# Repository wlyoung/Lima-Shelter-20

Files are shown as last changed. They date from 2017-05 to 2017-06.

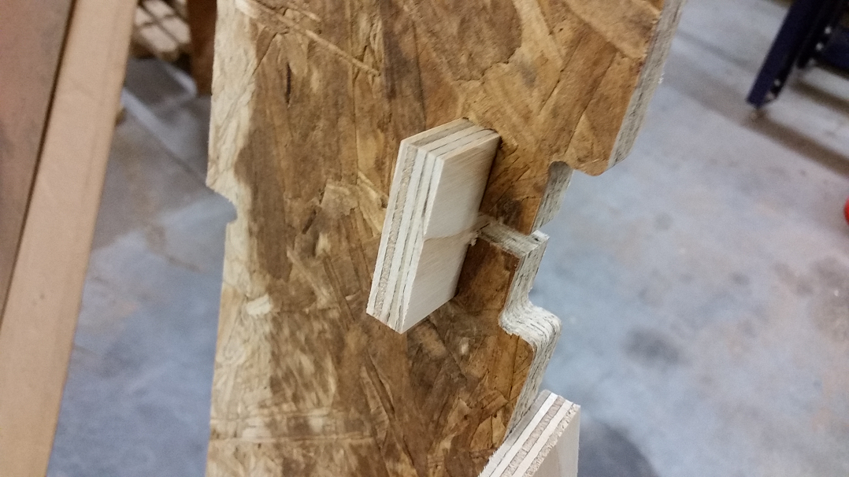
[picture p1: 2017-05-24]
images/fastener block in slot.png

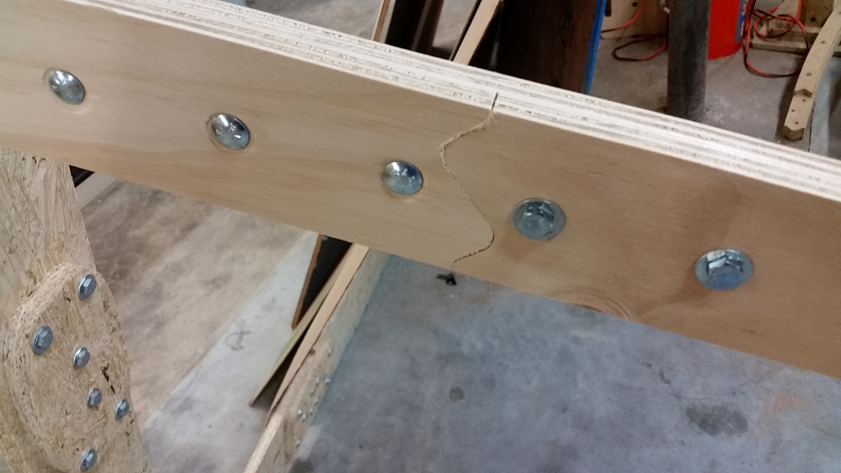
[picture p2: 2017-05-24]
images/carriage and hex bolts in splice plate.png

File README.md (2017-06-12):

# Lima Shelter 2.0

## About
Update of the Shelter 2.0 design to simplify the construction and and reduce material usage, using design details in the smaller 8x8 Shelter 2.0 design. 

Although several of the parts have been fabricated, a complete structure hasn't been built from thus design yet so there could be problems. Consider yourselves warned.

And just because someone will ask, it was named for the city in Peru and not the bean.

## Changes and issues

* The Lima Shelter has 2 more sheets of 1/2" material, but 11 less sheets of 3/4". 

* Everything is cut with a 1/4" bit

* The files are somewhat material agnostic, and can be made from material that's close to the designed size

* The half-lap connections in the rib parts have been replaced with bolted splice plates. They are both easier to assemble and much faster to cut

* The longitudinal slotted stringers that connect the ribs have been replaced with purlins that are fastened with screws into small plywood "wedges" that are cut from some of the 1/2" sheets. This allows the ribs to be narrower, giving more interior room. The use of these wedges allow us to fasten into the face of plywood instead of the edge, a much stronger connection.

* Shallow dimples (on their own layer in the files) mark the location of pilot holes for the screws. You can se these dimples to drill through holes with a hand drill and a bit sized for your crews, or tollpath tham as thru-holes and drill them with a seperate bit

* There's now one door instead of two...2 doors ended up being a pain! This also allowed us to create a solid wall version that only requires a few cutting mods, and mounting the trim pieces on the outside of the endwall, instead of on the inside for a door. The Sketchup model should help illustrate that

* This version doesn't have any windows. We haven't come up with a great idea for them and figured we would see what others came up with.

* Most of the bolts are now 1/4" or 6mm, and can be either hex bolts or carriage bolts (preferred). The only exception are the bolts holding the sleepers together...they are still 3/8". If using Hex bolts we recommend using flat washers under the head, and regardless of what kind of bolt you use, a washer under the nut is always a good idea.

* Several pieces of AtFAB furniture have been added to the waste areas of some of the 3/4" sheets. Thanks SO much to Ann and Gary for allowing us to include their designs. You may ONLY cut their furniture along with these Shelter files...if you want to cut more contact them at http://atfab.co/

* This work is licensed under the Creative Commons Attribution-NonCommercial 3.0 International License. To view a copy of this license, visit http://creativecommons.org/licenses/by-nc/3.0/ or send a letter to Creative Commons, PO Box 1866, Mountain View, CA 94042, USA.

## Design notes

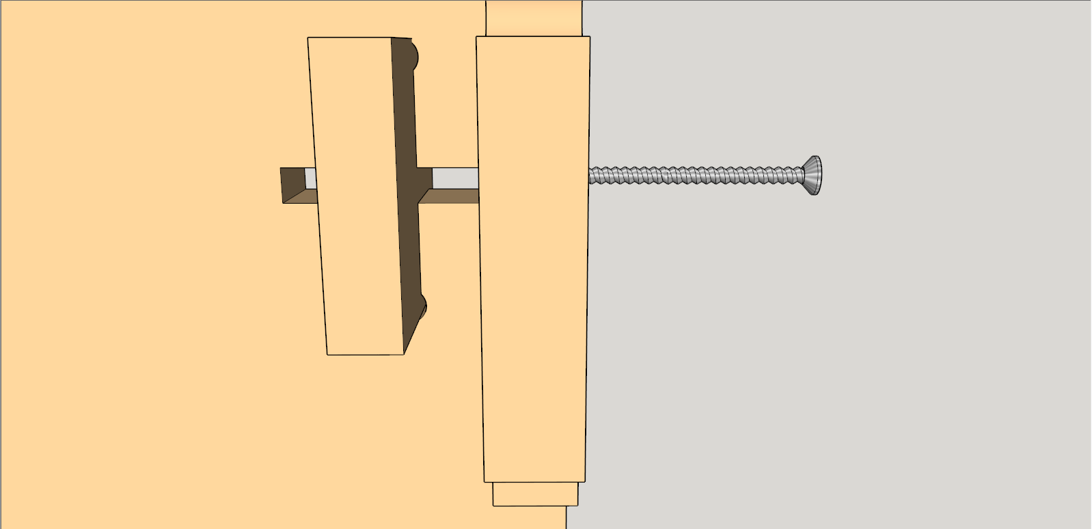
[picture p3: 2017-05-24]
images/attach purlins 2.png

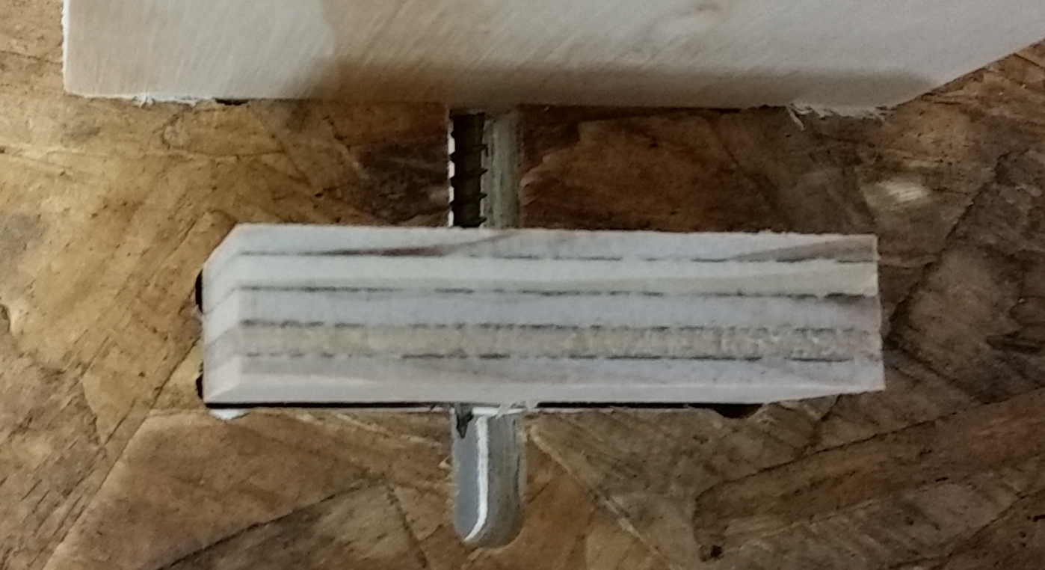
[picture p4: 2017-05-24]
images/screw detail.png

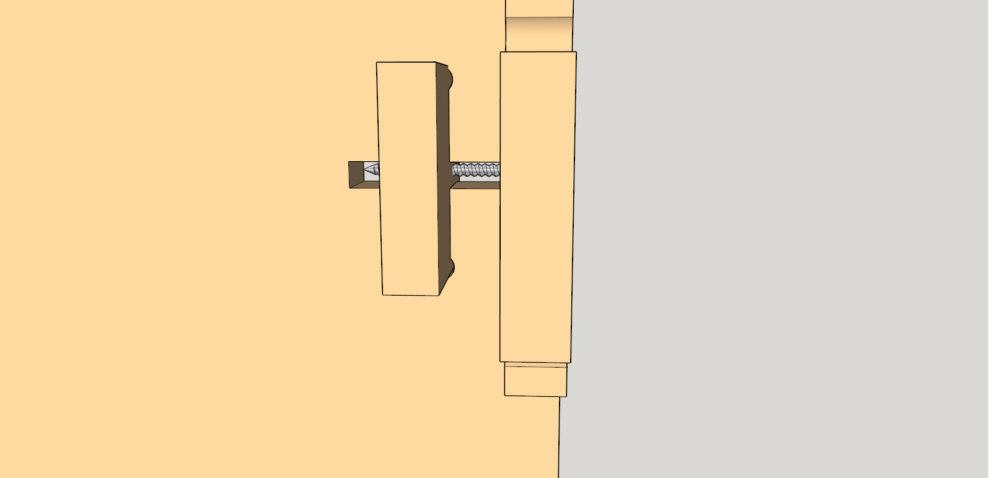
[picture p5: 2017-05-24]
images/attach purlins 3.png

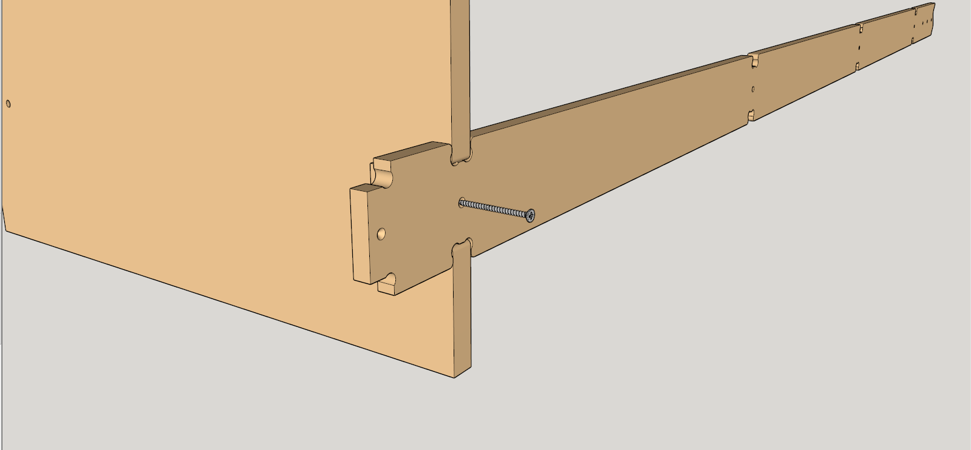
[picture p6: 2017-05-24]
images/attach purlins 1.png

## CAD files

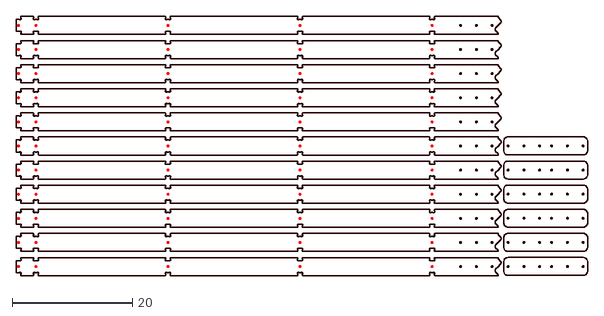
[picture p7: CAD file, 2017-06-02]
dxf/half inch/Lima Purlin cut 2.dxf
95.2 x 43.2

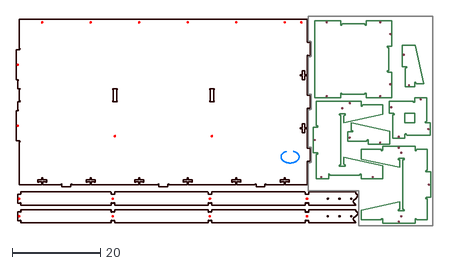
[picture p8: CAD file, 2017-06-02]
dxf/three quarter/Lima Floor edge short C and floor splice cut 1.dxf
94.5 x 47.5

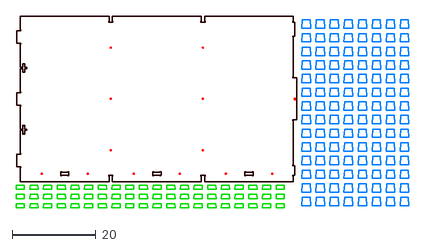
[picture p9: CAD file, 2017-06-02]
dxf/half inch/Lima Sidewall short and wedges cut 2.dxf
93.8 x 45.8

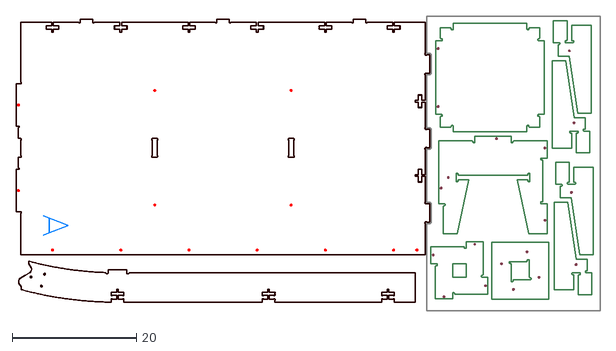
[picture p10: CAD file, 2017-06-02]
dxf/three quarter/Lima Floor edge short A and fascia cut 1.dxf
94.2 x 47.5

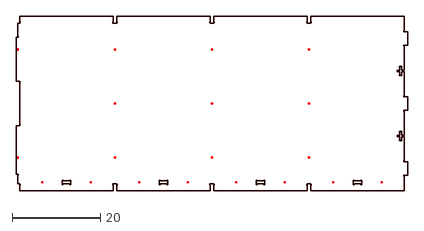
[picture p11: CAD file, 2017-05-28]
dxf/half inch/Lima Sidewall long cut 2.dxf
88.8 x 39.5

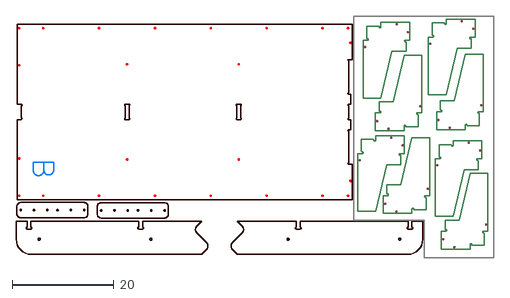
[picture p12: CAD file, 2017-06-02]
dxf/three quarter/Lima Floor center short B and sleeper parts and floor splice joiners cut 1.dxf
94.0 x 47.5

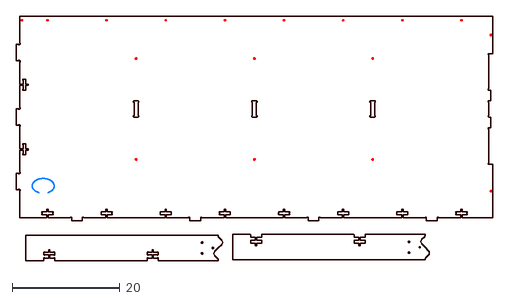
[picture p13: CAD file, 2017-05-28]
dxf/three quarter/Lima Floor edge long C and fascia cut 1.dxf
88.7 x 45.5

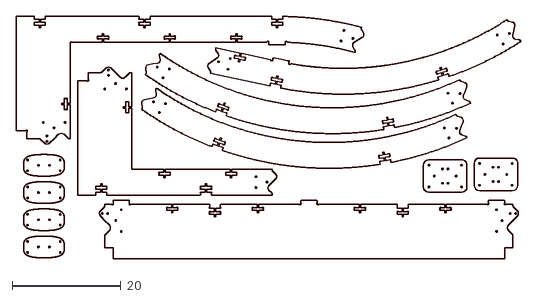
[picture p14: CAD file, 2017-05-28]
dxf/three quarter/Lima Ribs cut 6.dxf
92.8 x 44.6

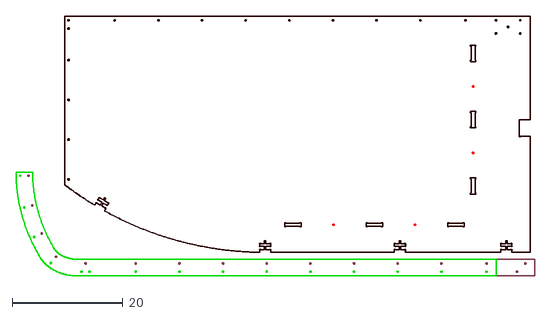
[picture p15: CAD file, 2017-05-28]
dxf/three quarter/Lima Endwall left cut 2.dxf
93.9 x 47.0

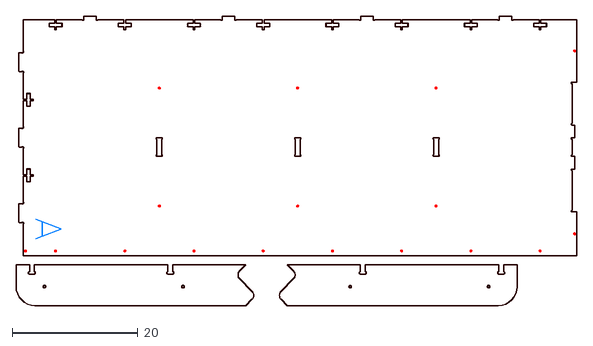
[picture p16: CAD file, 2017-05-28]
dxf/three quarter/Lima Floor edge long A and sleeper parts cut 1.dxf
89.1 x 45.9

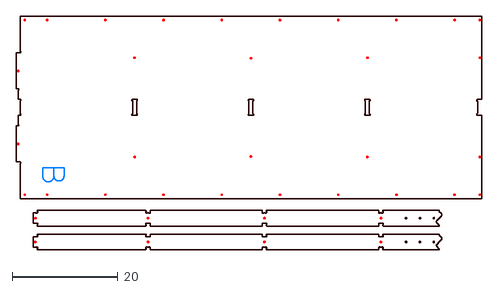
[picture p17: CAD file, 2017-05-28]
dxf/three quarter/Lima Floor center long B and floor splice cut 1.dxf
88.0 x 44.2

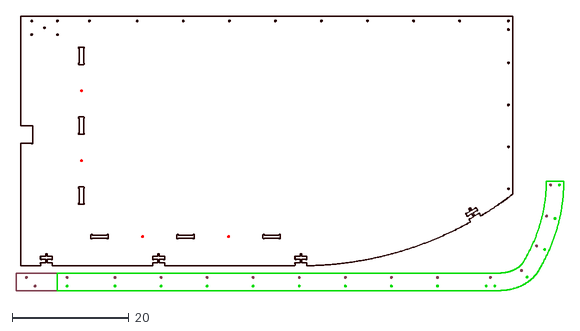
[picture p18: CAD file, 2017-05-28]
dxf/three quarter/Lima Endwall right cut 2.dxf
93.9 x 47.0

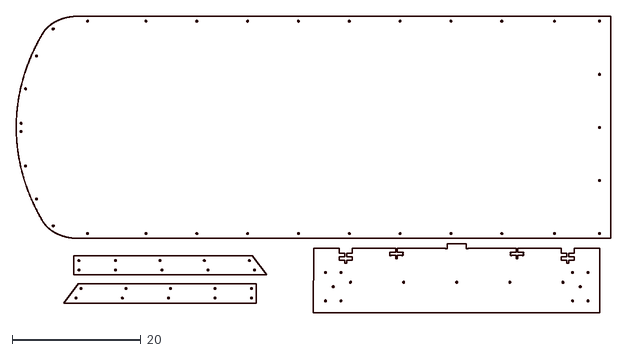
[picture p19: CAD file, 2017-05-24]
dxf/three quarter/Lima Endwall solid option parts cut 1.dxf
92.4 x 46.1

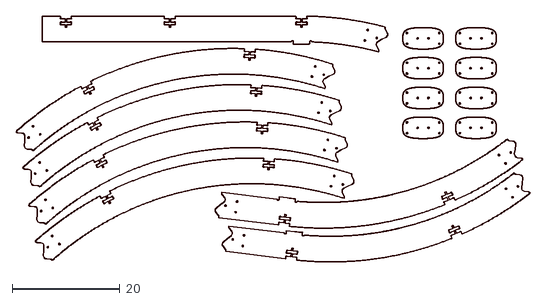
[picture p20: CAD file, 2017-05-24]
dxf/three quarter/Lima Fascia cut 1.dxf
95.2 x 45.5

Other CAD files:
dxf/three quarter/Lima Sleepers cut 2.dxf
dxf/three quarter/Lima Endwall door option parts cut 1.dxf
dxf/three quarter/Lima Endwall 2 headers cut 1.dxf
Sketchup/attachment detail.skp

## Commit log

2017-05-10 initial beta release
    First commit
    [Lima Endwall 2 headers cut 1.dxf, Lima Endwall door option parts cut 1.dxf, Lima Endwall left cut 2.dxf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]
2017-05-24 refining files and simplifying
    [Lima Floor center short B and sleeper parts and floor splice joiners cut 1.dxf, Lima Floor edge long A and sleeper parts cut 1.dxf, Lima Floor edge long C and 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]
2017-05-24 general cleanup
    A little bit of refinement housekeeping
    [Lima Endwall door option parts cut 1.dxf, Lima Endwall solid option parts cut 1.dxf, Lima Fascia cut 1.dxf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]
2017-05-28 cleaning up screw hole locations
    The dxf files are NOT in sync with these files. Will take care of that
    next
2017-05-28 mods and additions
    Added come connection points and files for screw wedges. Also added
    optional AtFAB furniture to waste areas of floor panels. Licence info to
    follow soon, but contact us if you need it quickly info@shelter20.com
    [Lima Endwall left cut 2.dxf, Lima Endwall right cut 2.dxf, Lima Floor center long B and floor splice cut 1.dxf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]
2017-06-02 Updates
    Synced dxf files with VCarve files. Added layer and perimeter in shorter
    floor panels for optional parts
    [Lima Floor center short B and sleeper parts and floor splice joiners cut 1.dxf, Lima Floor edge short A and fascia cut 1.dxf, Lima Floor edge short C and floor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]
